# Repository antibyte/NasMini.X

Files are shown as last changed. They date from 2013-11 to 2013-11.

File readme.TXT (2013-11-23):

Single Chip Nascom 2 Emulator

Credits:
Z80 Emulation :         : Marat Fayzullin http://fms.komkon.org/EMUL8/
Video and PS/2 based on : Katsumi http://hp.vector.co.jp/authors/VA016157/
SD & FAT Filesystem     : Elm Chan, Aiden Morrison, Riccardo Leonardi

What's working :

z80 CPU
24K RAM (2K used by video buffer and NAS-SYS)
10K ROM (2K NAS-SYS 3 and 8K Microsoft Basic)
Loading NAS format files from SD card(press F1)
Saving RAM to NAS format on SD card (press F2)
Composite Video 48x16 video output, advanced graphics character ROM is included.
PS/2 keyboard with special keys:
  F1 - Load NAS file from SD card (works for BASIC)
  F2 - Save RAM (0x0100-0x7000) as NAS file to SD card (works for BASIC)
  Scroll lock - Trigger NMI
Single step emulation
RS232 is partialy working. Received Data is corrupted, maybe hardware
problem, as is used a Bluetooth adapter. 

ToDo :

Cassette Emulation (real or/and SD)
RS232 bootloader (if possible)
Map Z80PIO access to I2C Port expander, or remaining physical pins ?

Speed:
Maybe slower than the real thing, but really usable.

Thoughts:
A PIC32MX250 is used featuring USB, but there is not enought space left for any
USB stack.
But as the price difference to the non-USB MX150 is negligible for small
projects, it may be good to have it on board for possible reuse in future
projects.

First steps:
Visit http://www.nascomhomepage.com/
 
Type "J" after start to jump to Microsoft Basic
Most NAS files load to 0x01000. Type E1000 to run them

antibyte 11/2013

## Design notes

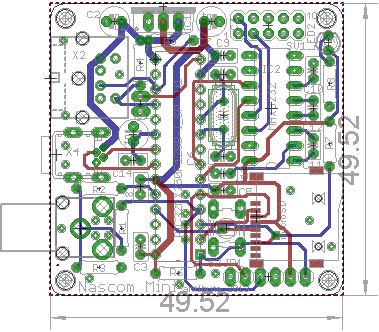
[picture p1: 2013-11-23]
NasMini.png

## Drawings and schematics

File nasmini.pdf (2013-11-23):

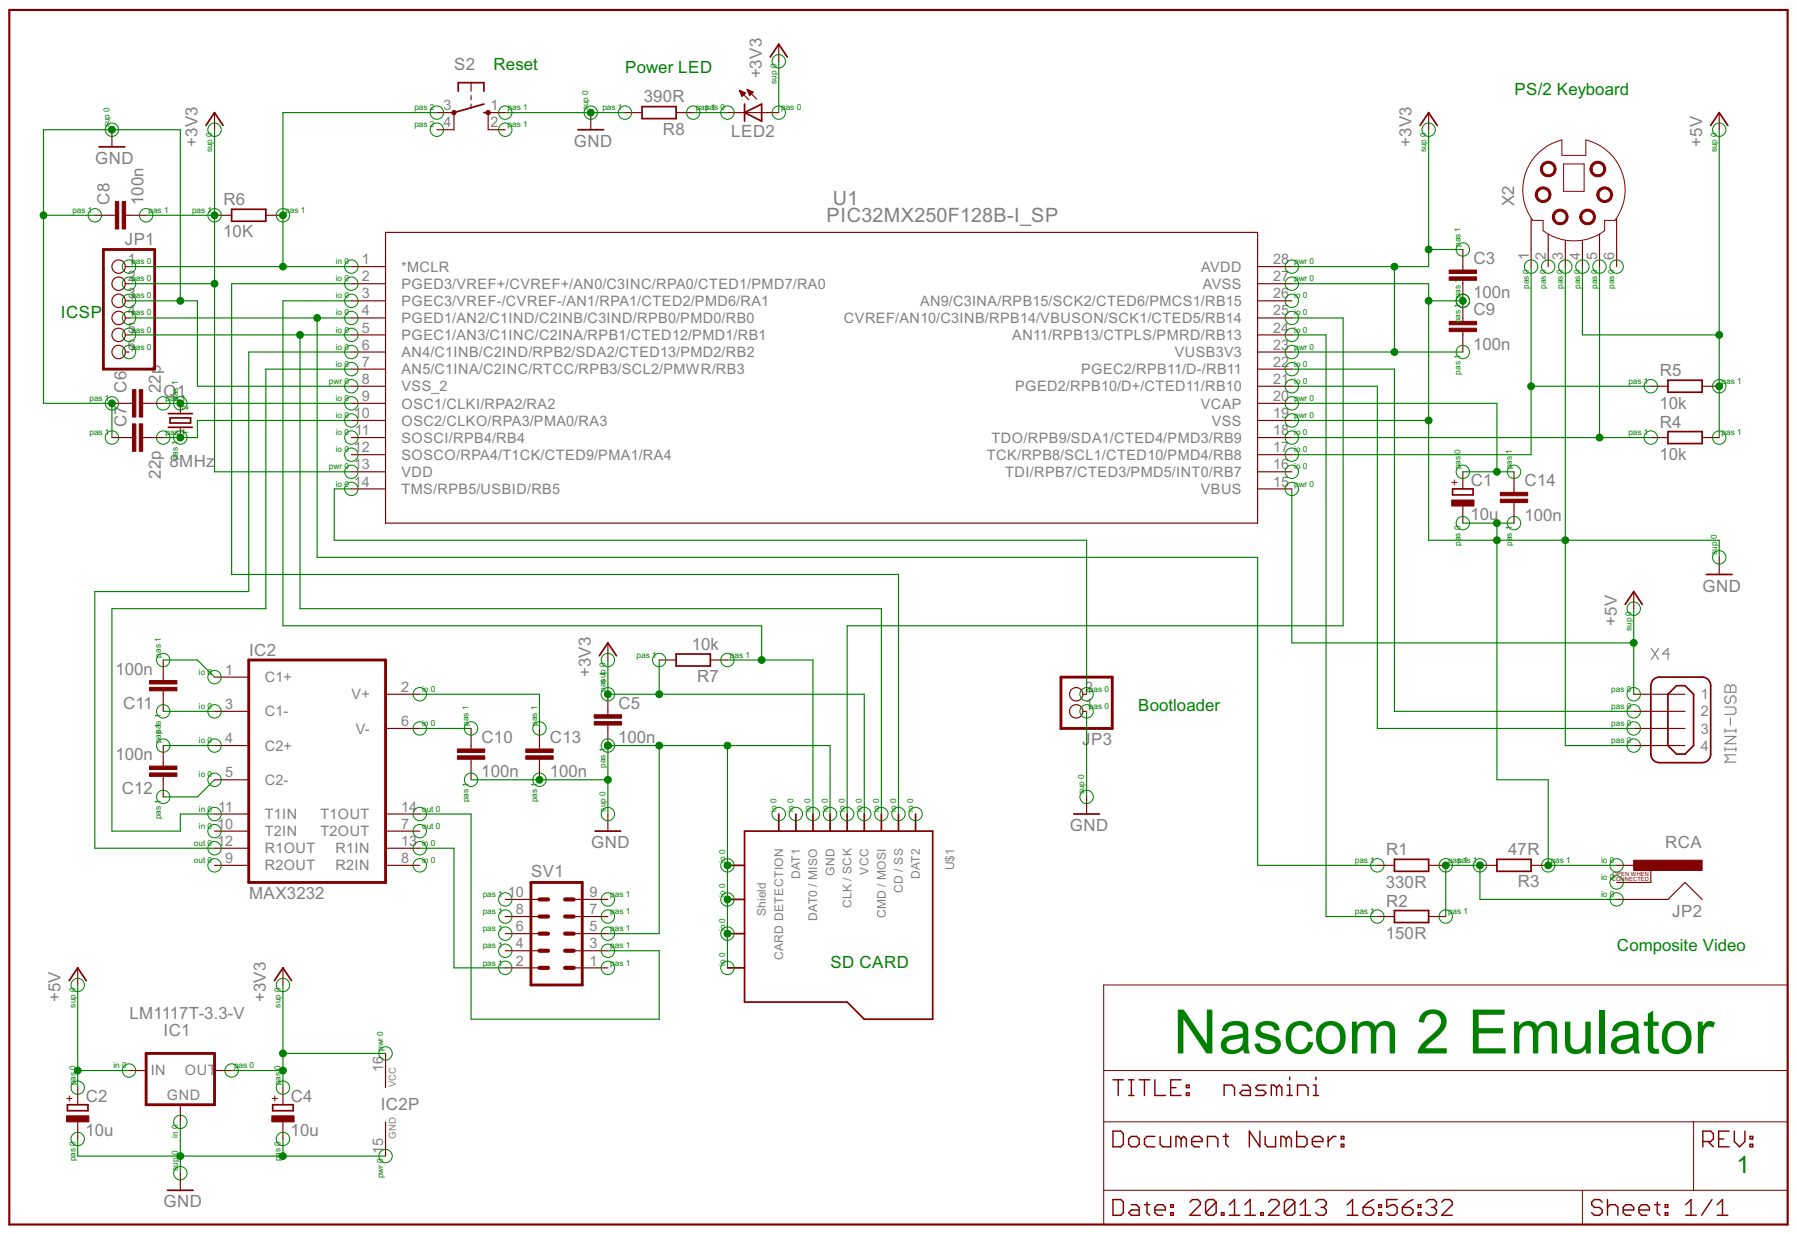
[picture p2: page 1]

17 TDO/RPB9/SDA1/CTED4/PMD3/RB9 io 0 | 10k
16 TCK/RPB8/SCL1/CTED10/PMD4/RB8

pas 1 pas 1

DAT2 CD / SS CMD / MOSI DAT0 / MISO

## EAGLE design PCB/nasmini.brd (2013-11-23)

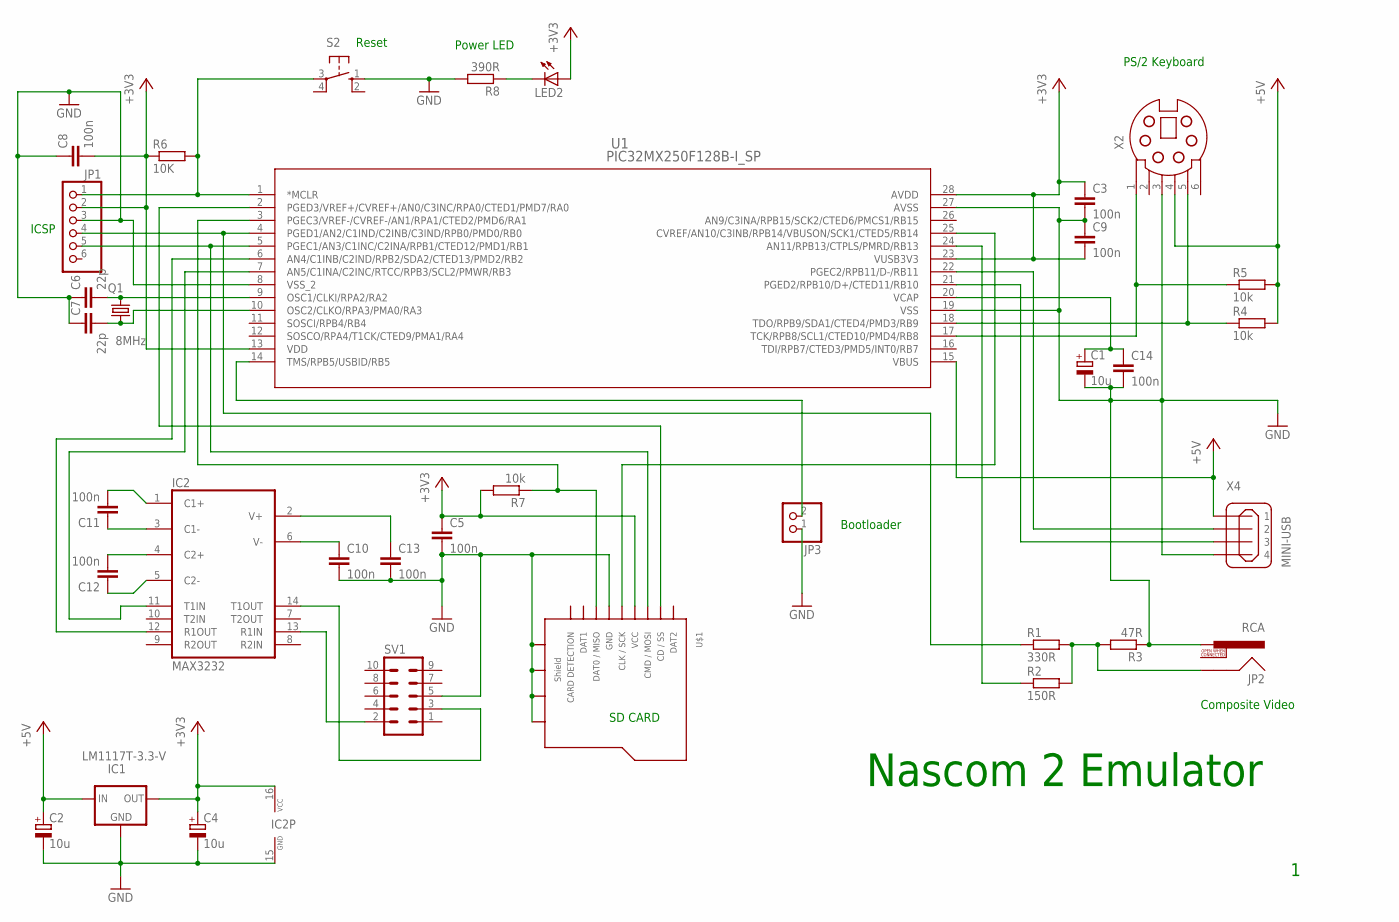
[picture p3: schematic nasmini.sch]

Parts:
C1, C2, C4: 10u; E2,5-5
C3, C5, C8, C9, C10, C11, C12, C13, C14: 100n; C025-025X050
C6, C7: 22p; C025-025X050
IC1: LM1117T-3.3-V; TO220V
IC2: MAX3232; DIL16
JP1: PINHD-1X6; 1X06
JP2: RCA
JP3: PINHD-1X2; 1X02
LED2: LED3MM
Q1: 8MHz; HC49/S
R1: 330R; 0207/7
R2: 150R; 0207/7
R3: 47R; 0207/7
R4, R5, R7: 10k; 0207/7
R6: 10K; 0207/7
R8: 390R; 0207/7
S2: 10-XX; B3F-10XX
SV1: MA05-2
U1: PIC32MX250F128B-I_SP; SPDIP28_300MC
U$1: MICROSD_CARD_POLLIN; MR**-AP*03**
X2: MDSSV-F06; SSV-BC06
X4: MINI-USB; 85-32006-201-1

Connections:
+3V3: C3.1, C4.+, C5.1, C8.2, C9.2, IC1.2 (OUT), IC2.16 (VCC), JP1.2, LED2.A, R6.1, R7.2, U1.13 (VDD), U1.23 (VUSB3V3), U1.28 (AVDD), U$1.VCC
+5V: C2.+, IC1.3 (IN), R4.2, R5.2, U1.15 (VBUS), X2.4, X4.1
GND: C1.-, C2.-, C3.2, C4.-, C5.2, C6.1, C7.1, C8.1, C9.1, C10.2, C13.2, C14.2, IC1.1 (GND), IC2.15 (GND), JP1.3, JP2.PIN, JP3.1, R3.1, R8.2, S2.1 (S), SV1.5, U1.8 (VSS_2), U1.19 (VSS), U1.27 (AVSS), U$1.GND, U$1.SHD_1 (SHD1), U$1.SHD_2 (SHD2), U$1.SHD_3 (SHD3), U$1.SHD_4 (SHD4), X2.3, X4.4
unnamed: R5.1, U1.17 (TCK/RPB8/SCL1/CTED10/PMD4/RB8), X2.1
unnamed: R4.1, U1.18 (TDO/RPB9/SDA1/CTED4/PMD3/RB9), X2.5
unnamed: R2.1, U1.24 (AN11/RPB13/CTPLS/PMRD/RB13)
unnamed: JP3.2, U1.14 (TMS/RPB5/USBID/RB5)
unnamed: JP2.SHELL, R1.2, R2.2, R3.2
unnamed: IC2.13 (R1IN), SV1.2
unnamed: C1.+, C14.1, U1.20 (VCAP)
unnamed: JP1.4, R1.1, U1.4 (PGED1/AN2/C1IND/C2INB/C3IND/RPB0/PMD0/R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)
unnamed: JP1.1, R6.2, S2.3, U1.1 (*MCLR)
unnamed: U1.25 (CVREF/AN10/C3INB/RPB14/VBUSON/SCK1/CTED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), U$1.CLK (CLK/SCK)
unnamed: U1.2 (PGED3/VREF+/CVREF+/AN0/C3INC/RPA0/CTED1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), U$1.DAT3/CS (CD/SS)
unnamed: R7.1, U1.3 (PGEC3/VREF-/CVREF-/AN1/RPA1/CTED2/PMD6/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), U$1.DAT0 (DAT0/MISO)
unnamed: JP1.5, U1.5 (PGEC1/AN3/C1INC/C2INA/RPB1/CTED12/PMD1/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), U$1.CMD (CMD/MOSI)
unnamed: U1.21 (PGED2/RPB10/D+/CTED11/RB10), X4.3
unnamed: C7.2, Q1.1, U1.10 (OSC2/CLKO/RPA3/PMA0/RA3)
unnamed: C6.2, Q1.2, U1.9 (OSC1/CLKI/RPA2/RA2)
unnamed: U1.22 (PGEC2/RPB11/D-/RB11), X4.2
unnamed: C13.1, IC2.2 (V+)
unnamed: C10.1, IC2.6 (V-)
unnamed: C12.1, IC2.5 (C2-)
unnamed: C12.2, IC2.4 (C2+)
unnamed: C11.1, IC2.3 (C1-)
unnamed: C11.2, IC2.1 (C1+)
unnamed: IC2.11 (T1IN), U1.7 (AN5/C1INA/C2INC/RTCC/RPB3/SCL2/PMWR/RB3)
unnamed: IC2.12 (R1OUT), U1.6 (AN4/C1INB/C2IND/RPB2/SDA2/CTED13/PMD2/R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)
unnamed: LED2.K (C), R8.1
unnamed: IC2.14 (T1OUT), SV1.3

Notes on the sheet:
Composite Video
PS/2 Keyboard
Nascom 2 Emulator
ICSP
SD CARD
Power LED
Reset
Bootloader

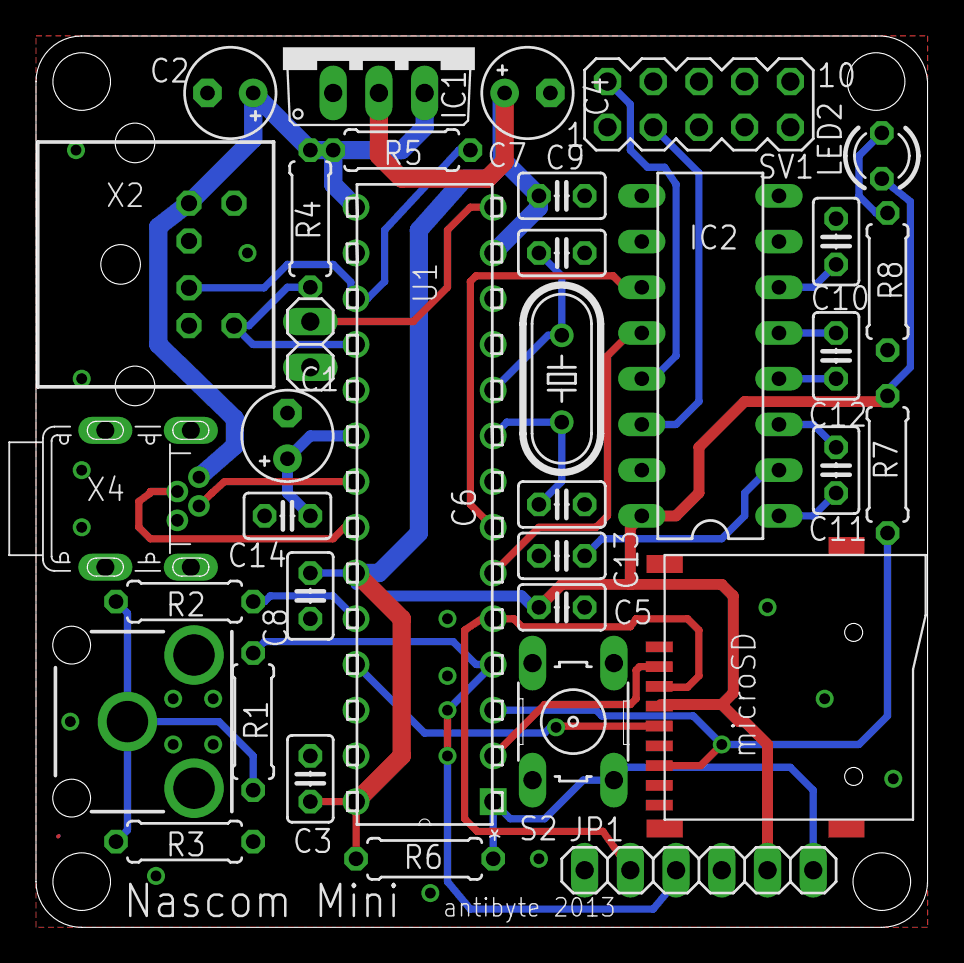
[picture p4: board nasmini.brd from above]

Board: 2 copper layers, 49.5 x 49.5 mm, 35 parts (0 on the bottom side), 30 nets.

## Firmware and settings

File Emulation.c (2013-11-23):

/* 
 * File:   Emulation.c
 * 
 * Authors and License :
 * Z80 Emulation:  Marat Fayzullin - free for noncommercial use
 * Video, PS/2 : Katsumi - licenced under LGPL 
 * FAT Filesystem : Elm Chan - free, unrestricted use
 * PIC32 FAT FS adaption : Aiden Morrison, Riccardo Leonardi
 * Nascom emulation : antibyte - free, unrestricted use
 *
 */

#define GetSystemClock()     (48000000ul)
#define GetPeripheralClock()    (GetSystemClock())
#define GetInstructionClock()   (GetSystemClock())

#include <stdio.h>
#include <stdlib.h>
#include <plib.h>
#include <peripheral/osc.h>
#include <peripheral/system.h>

#include "./Z80/Z80.h"
#include "./Z80/GenericTypeDefs.h"
#include "./Z80/Compiler.h"
#include "./z80/msbasic.h"
#include "./z80/nsys3.h"
#include "./Z80/Compiler.h"

#include "./emulation.h"
#include "./Video/video.h"
#include "./ps2.h"
#include "./fatfs/ff.h"
#include "./fatfs/diskio.h"
#include "./uart.h"
#include <sys/attribs.h>

/*
 * 
 */
#pragma config PMDL1WAY = OFF           // Allow multiple reconfigurations
#pragma config IOL1WAY  = OFF           // Allow multiple reconfigurations
#pragma config FPLLIDIV = DIV_2
#pragma config FPLLMUL  = MUL_24
#pragma config FPLLODIV = DIV_2
#pragma config FPBDIV   = DIV_1         // Peripheral Clock divisor
#pragma config UPLLEN   = OFF            // USB PLL Enable
#pragma config UPLLIDIV = DIV_2         // USB PLL Divider
#pragma config FVBUSONIO = OFF          // VBUS pin control
#pragma config FUSBIDIO = OFF           // USBID pin control
#pragma config FWDTEN   = OFF           // Watchdog Timer
#pragma config WDTPS    = PS1           // Watchdog Timer Postscale
#pragma config FCKSM    = CSDCMD        // Clock Switching & Fail Safe Clock Monitor
#pragma config OSCIOFNC = OFF           // CLKO Enable
#pragma config POSCMOD  = HS            // Primary Oscillator
#pragma config IESO     = OFF           // Internal/External Switch-over
#pragma config FSOSCEN  = OFF           // Secondary Oscillator Enable
#pragma config FNOSC    = PRIPLL        // Oscillator Selection
#pragma config CP       = OFF           // Code Protect
#pragma config BWP      = OFF           // Boot Flash Write Protect
#pragma config PWP      = OFF           // Program Flash Write Protect
#pragma config ICESEL   = ICS_PGx1      // ICE/ICD Comm Channel Select
#pragma config JTAGEN   = OFF           // Disable JTAG

#ifdef __DEBUG
#pragma config DEBUG = ON				// Background Debugger ON or OFF
#else
#pragma config DEBUG = OFF				// Background Debugger ON or OFF
#endif


unsigned char memory[maxmem];   // the emulated memory
char keyscan_counter;           // row counter for keymatrix scan
char key_reset;                 // reset keymatrix counter
unsigned char tape_led=0;       // tape_led state
unsigned char single_step=0;    // single_step circuit state
unsigned char serial_data=0;
unsigned char mounted=0;
unsigned char have_disk=0;
unsigned char loadrequest=0;
unsigned char fileNname[15];    // filename buffer

FRESULT FOpenRes;

Z80 engine;

FATFS Fatfs;
FATFS *fs;				/* Pointer to file system object */
FIL file;               		/* File objects */
volatile BYTE rtcYear = 111, rtcMon = 11, rtcMday = 22;	// RTC starting values
volatile BYTE rtcHour = 0, rtcMin = 0, rtcSec = 0;

//Work registers for fs command
DWORD acc_size;			/* Work register for fs command */
WORD acc_files, acc_dirs;
FILINFO Finfo;
const BYTE ft[] = {0,12,16,32};

#define TOGGLES_PER_SEC		1000
#define CORE_TICK_RATE	       (GetSystemClock()/2/TOGGLES_PER_SEC)


int main(int argc, char** argv) {

    SYSTEMConfig(GetSystemClock(), SYS_CFG_WAIT_STATES | SYS_CFG_PCACHE);

   /* USBDeviceInit();
    if ( USBGetDeviceState() == DETACHED_STATE ) {
        USBDeviceAttach();
    }*/

    ANSELA = 0;
    ANSELB = 0; //all ports digital

    INTEnableSystemSingleVectoredInt();
    INTEnableSystemMultiVectoredInt();

    // Software RTC for FAT Filesystem
    OpenCoreTimer(CORE_TICK_RATE);			// Open 1 ms Timer
    // set up the core timer interrupt with a prioirty of 2 and zero sub-priority
    mConfigIntCoreTimer((CT_INT_ON | CT_INT_PRIOR_2 | CT_INT_SUB_PRIOR_0));
    
    initVideo();                // start the video engine
    initPS2();                  // setup keyboard
    initUART();                 // setup RS232

    if (!disk_initialize(0))    // initialize sd card
    {
        have_disk=1;
        f_mount(&Fatfs,"/",1);
    }

    engine.IPeriod=500;         // Call 'LoopZ80' every 500 Z80 clocks
    ResetZ80(&engine);         
    uart_putc('X');
    while(1)
    {
      RunZ80(&engine);          // Start Z80 emulation
    }
    return (EXIT_SUCCESS);
}

void WrZ80(register word Addr,register byte Value) // handles Z80 memory writing
{
    word tladdr,vline,vcol;
    tladdr=(Addr-0x800);

    if (Addr>=0x0c00 && Addr<maxmem)
        memory[tladdr]=Value; // write to ram
    else if (Addr>=0x800 && Addr<0xc00)   // access to video ram ?
    {
        if (tladdr>9)   // visible area starts at vram+10
        {               // translate to video engine buffer
            vline=tladdr>>6;
            vcol=tladdr>73?tladdr%64-10:tladdr-10;
            if (vline<15 && vcol<49)
                VRAM[48+vline*48+vcol]=Value;
            if (vline==15 && vcol<48)   // last line in vram is first on screen
                VRAM[vcol]=Value;
        }
        memory[tladdr]=Value;   // store in ram
    }
    return;

}
byte RdZ80(register word Addr)  // handles Z80 memory reading
{
    if (Addr < 0x800)                // 0x000-0x800 is monitor rom
        return nsysrom[Addr];
    else if (Addr < 0x800+maxmem)    // 0x1000-0x7000 is ram
        return memory[Addr-0x800];

    if (Addr>=0xe000)                // 0xe000-0xffff is basic rom
        return basrom[Addr-0xe000];
    return 0;
}

void OutZ80(register word Port,register byte Value)

{
    word pt = Port & 0x00ff;

    switch(pt)
    {
        case 0:
            if (Value&0x01)
                keyscan_counter++;  // scan next keyboard row
            if (Value&0x02)
                keyscan_counter=0;  // reset keyboard matrix counter
            tape_led=!!(Value&0x10);
            if (Value&0x08)         // Single step circuit triggered ?
                engine.Trap=1;
            break;
        case 1:
            uart_putc(Value);
            break;

    }
}

byte InZ80(register word Port)

{
    word pt = Port & 0x00ff;

    switch(pt)
    {
        case 0:         // keyboard matrix scan result (inverted)
             return ~(keyscan_buffer[keyscan_counter]);
        case 1:         // read serial data
            if (uart_rx_count)
            {
                
                //uart_rx_count--;
                return uart_rx_buff[--uart_rx_count];
            }
            return 0;
    
        case 2:         // read serial port status byte
             return 64 | (uart_rx_count ? 128:0);

        default:
             return 0;
    }
}

word LoopZ80(register Z80 *R)   // called periodically from Z80 emulation

{
    getkey();                   // Check for keypress

    if (key_nmi)                // scroll lock was pressed, trigger NMI
    {
        key_nmi=0;
        return INT_NMI;
    }

    if (edit_mode && have_disk)           // F1 - User wants to load "*.NAS" file
    {
        if (req_action==1)
        {
            if (get_filename(fileNname, "NAS format file loading:" ) && !!fileNname[0])
            {
                if (open_file(fileNname,FA_READ))
                {
                    load_nas();
                    close_file();
                    return INT_NONE;
                } else
                    if (!!fileNname[0]);
                        user_info("Fatal Error:", "Could not open the requested file !");
            }
        } else if (req_action==2)       // F2 - User wants to save to "*.NAS" file
        {
            if (get_filename(fileNname, "NAS format memory dump (0x1000-0x7000)." ) && !!fileNname[0])
            {
                if (open_file(fileNname,FA_WRITE))
                {
                    save_nas();
                    close_file();
                    return INT_NONE;
                } else
                    if (!!fileNname[0]);
                        user_info("Fatal error;", "Could not open the requested file !");
            }            
        }
        req_action=0;
    }

    if (tape_led && have_disk && !mounted)
    {
        // todo: cassette emulation
    }
        
    return INT_NONE;

}

void PatchZ80(register Z80 *R)
{
   
}

void save_nas()
{
    if (!have_disk)
        return;

    unsigned char haddr[4];
    unsigned char val[2];
    char eol[4]={0x08,0x08,0x0d,0x0a};
    char eofm[3]={'.',0x0d,0x0a};
    unsigned char r;
    int c;
    unsigned int cksum=0;
    unsigned int wcnt;

    for (c=0;c<maxmem-0x800;c+=8)
    {
        nas_val2hex(0x1000+c,haddr,4);
        cksum+=(0x1000+c)>>2&0x00ff;
        cksum+=(0x1000+c)&0x00ff;
        f_write(&file, &haddr,4,&wcnt);
        f_write(&file, " ",1,&wcnt);
        for (r=0;r<8;r++)
        {
            nas_val2hex(memory[0x800+c+r],val,2);
            cksum+=memory[0x800+c+r];
            f_write(&file, &val,2,&wcnt);
            f_write(&file, " ",1,&wcnt);
        }
        nas_val2hex(cksum&0x00ff,val,2);
        cksum=0;
        f_write(&file, val,2,&wcnt);
        f_write(&file, &eol,4,&wcnt);
    }
    f_write(&file, &eofm,3,&wcnt);
}

/* Load a file in NAS format
   Every line starts with the target addr. followed by
   eight bytes of data and a one byte checksum.
   ASCII format ----------------->|
   AAAA 01 02 03 04 05 06 07 08 09 0x08 0x08 0x0d 0x0a
   checksum is low byte of AA+AA+01 ... +08
   Last line contains only a dot '.' and CR/LF */

void load_nas()
{

    if (!have_disk)
        return;

    BYTE haddr[4];
    BYTE hval[2];
    WORD taddr;
    WORD tval;
    UINT bread=0;
    char l;

    for(;;)
    {
        f_read(&file,&haddr,4,&bread);
        if (haddr[0]=='.') // done if first char in line is a dot
            goto done;
        if (bread!=4) //EOF
            goto err;
        taddr=nas_hex2val(haddr,4);
        if (taddr<0x1000 || taddr>maxmem+0x1000)
        {
            printchar2(0,taddr>>8);
            printchar2(2,taddr&&0x00ff);
            //v_print(10);
            //v_print(haddr);
            while(1);
            user_info("Fatal Error:","Target address outside of allowed range.");
            return;
        }
        for (l=0;l<8;l++)
        {
            f_read(&file, &hval,1,&bread); //dummy (blank)
            f_read(&file, &hval,2,&bread);
            if (!!!bread) //EOF
                goto err;
            memory[taddr-0x800+l]=nas_hex2val(hval,2);
        }
        while (1)
        {
            f_read(&file, &hval,1,&bread);
            if (!bread) //EOF
                goto err;
            if (hval[0]==0x0a) // line finished
                break;
        }
    }
err:
    user_info("Fatal Error:","Unexpected end of file.");
done:
    return;

}

WORD nas_hex2val (char* haddr,BYTE len)
{
    int rval,i=0;
    while (len--)
    {
        rval<<=4;
        rval|=(haddr[i]<='9'?haddr[i]-'0':haddr[i]-'A'+10);
        i++;
    }
    return rval;
}

void nas_val2hex(WORD val, char* hex, BYTE len)
{
	int ch, i = 0;
	while (len--)
	{
		ch = val & 0x000f;
		hex[len] = (ch > 9 ? 'A' + ch-10 : '0' + ch);
			val >>= 4;
	}
}

unsigned char get_filename(char *fname,char *desc_text)
{
    BYTE x=0;
    save_vram();    // save a copy of the screen
    printchar(12);
    v_print(desc_text);
    printchar(10);
    v_print("Enter Filename or press ESC to exit. ");
    printchar(10);
    while (edit_keybuff!='*') // escape='*'
    {
        getkey();
        if (edit_newkey)
        {
            switch(edit_keybuff)
            {
                case('+'):  // enter
                    if (x==0)
                    {
                        fname[0]=0;
                    } else
                    {
                        memcpy(fname,VRAM+96,x);
                        fname[x]=0;
                    }
                    restore_vram();
                    edit_mode=edit_keybuff=edit_newkey=0;
                    return 1;
                 case ('-'):    // backspace
                    printchar (8);
                    if (x>0)
                        x--;
                    edit_newkey=0;
                    continue;
                default:
                    if (x<12)
                    {
                        edit_newkey=0;
                        printchar (edit_keybuff);
                        x++;
                    }
            }
        }
    }
    edit_mode=edit_keybuff=edit_newkey=0;
    restore_vram(); // restore original screen
    return 0;
}


unsigned char open_file (char *fname, unsigned char mode)
{
    FRESULT FOpenRes;
    long accessmode;
    accessmode=(mode==FA_READ)?(FA_READ | FA_OPEN_EXISTING):(FA_OPEN_ALWAYS | FA_CREATE_ALWAYS |FA_WRITE );
    FOpenRes=f_open(&file, fname, (BYTE)accessmode);
    return (FOpenRes==FR_OK)?1:0;
}

void close_file ()
{
    f_close(&file);
}

void user_info(char *info,char *text)
{
    edit_mode=1;
    save_vram();
    printchar(12);
    v_print(info);
    printchar (10);
    v_print(text);
    printchar (10);
    printchar (10);
    v_print("Press ESC to continue.");
    printchar(10);
    while (edit_keybuff!='*')
        getkey();
    restore_vram();
    edit_mode=0;
}


/*****************************************************************************
 * Function:  		void CoreTimerHandler(void)
 * PreCondition:
 * Input:           None
 * Output:          None
 * Side Effects:
 * Overview:        FatFs requires a 1ms tick timer to aid
 *					with low level function timing
 * Note:            Initial Microchip version adapted to work into ISR routine
 *****************************************************************************/
void __ISR(_CORE_TIMER_VECTOR, IPL2SOFT) CoreTimerHandler(void)
{
	static const BYTE dom[12] = {31, 28, 31, 30, 31, 30, 31, 31, 30, 31, 30, 31};
	static int div1k;
	unsigned char n;

	// clear the interrupt flag
	mCTClearIntFlag();
    // update the period
    UpdateCoreTimer(CORE_TICK_RATE);

	disk_timerproc();	// call the low level disk IO timer functions

	// implement a 'fake' RTCC
	if (++div1k >= 1000) {
		div1k = 0;
		if (++rtcSec >= 60) {
			rtcSec = 0;
			if (++rtcMin >= 60) {
				rtcMin = 0;
				if (++rtcHour >= 24) {
					rtcHour = 0;
					n = dom[rtcMon - 1];
					if ((n == 28) && !(rtcYear & 3)) n++;
					if (++rtcMday > n) {
						rtcMday = 1;
						if (++rtcMon > 12) {
							rtcMon = 1;
							rtcYear++;
						}
					}
				}
			}
		}
	}
}


/*********************************************************************
 * Function:  		DWORD get_fattime(void)
 * PreCondition:
 * Input:           None
 * Output:          Time
 * Side Effects:
 * Overview:        when writing fatfs requires a time stamp
 *					in this exmaple we are going to use a counter
 *					If the starter kit has the 32kHz crystal
 *					installed then the RTCC could be used instead
 * Note:
 ********************************************************************/
DWORD get_fattime(void)
{
	DWORD tmr;

	INTDisableInterrupts();
	tmr =	  (((DWORD)rtcYear - 80) << 25)
			| ((DWORD)rtcMon << 21)
			| ((DWORD)rtcMday << 16)
			| (WORD)(rtcHour << 11)
			| (WORD)(rtcMin << 5)
			| (WORD)(rtcSec >> 1);
	INTEnableInterrupts();

	return tmr;
}


/** EOF main.c *************************************************/

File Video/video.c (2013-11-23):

/*
   This program is provided under the LGPL license ver 2.
   Written by Katsumi.
   http://hp.vector.co.jp/authors/VA016157/
   kmorimatsu@users.sourceforge.jp
   -------
   Converted to PAL Timings and NASCOM resolution by antibyte 11/2013
   This creates a 48x16 character display.
   Font is 8x16, so final resolution is 384x256
   Allmost all modern TV's should be able to handle both PAL and NTSC.
   Nascom produced a 8x12 cut font version for sale in NTSC regions.

 ****** NOTE: ignore values in comments, most are still ntsc based *****

 
 */

#include <plib.h>
#include "video.h"
#include "cgrom.h"
#include "./../ps2.h"
#include "./../emulation.h"


/*

PAL:

  	Raster frequency is 15625 hz, so one raster takes 64 usecs.
	Use 3072 clocks, resulting in 15625 hz
	Note that 512 clocks of 8 MHz (=SPI clock speed) also produces the same frequency.

 */

/*	Minimum time between two interruption events is 2.3 usecs,
	that corresponds to 92 clocks.
*/

// RB0=Sync
#define sync LATBbits.LATB0 //remapped for better PCB layout ,was 13
#define toggleSync() LATBINV=0x01 // remapped, was 2000
#define hclocks 3072

unsigned char VRAM[84*16];  // video buffer
unsigned char VRAM2[84*16]; // video backup buffer

void initVideo(){
	unsigned long i;
        for (i=0;i<0x0300;i++) {
		VRAM[i]=32;
	}
	g_ntscVisible=1;
	g_Vsync=1;
	sync=1;

	// RB13 and RA4 are output pins
	TRISBbits.TRISB0=0; // was A4
	TRISBbits.TRISB13=0;

	// Timer2 is used for sync signal
	// On, Stop in Idle Mode, PBCLK, 1:1 prescale, 16-bit mode
	// Enable interrupt as priority 7
	TMR2=0;
	PR2=0xFFFF;
	T2CON=0xA000;
	T2CONbits.ON=1;
	IPC2bits.T2IP=7;
	IPC2bits.T2IS=0;
	IFS0bits.T2IF=0;
	IEC0bits.T2IE=1;

	// Timer4 is used for video signal
	// Off, Stop in Idle Mode, PBCLK, 1:2 prescale, 16-bit mode
	// Enable interrupt as priority 6
	TMR4=0;
	PR4=0xFFFF;
	T4CON=0x2010;
	IPC4bits.T4IP=6;
	IPC4bits.T4IS=0;
	IFS0bits.T4IF=0;
	IEC0bits.T4IE=1;

	// SPI2 module settings follow
	// PBCLOCK, Enable SPI2, Stop in Idle Mode, Enable SDO, 32 bit mode,
	// SS pin not used, Master mode, Disable SDI
	// SPI clock=REFCLK/(2x(SPI2BRG+1))=8 Mhz. (REFCLK=48 Mhz; SPI2BRG=2)
	// All extended setting are off (SPI2CON2).

	SPI2CON=0x0100A83C;
	SPI2CON2=0x0300;
	SPI2BRG=2;
	// Output SDO2 RB13 - remapped, was RA4
        RPB13R=0x04;
}

/*	PAL Sync signals:
	raster 1-3: L for 2.3 usecs, H for 29.5 usec, L for 2.3 usecs, H for 29.5 usec
	(110)         (110)
	2.3u__________2.3u__________                 110+1414+110+1414=3048
	|__|          |__|          
	       29.5u         29.5u
          (1414)        (1414)

	raster 4-6: L for 27.1 usecs, H for 4.7 usec, L for 27.1 usecs, H for 4.7 usec
      (1299)        (1299)
	   27.1u    __   27.1u    __                 1299+225+1299+225=3048
	|__________|  |__________|  
	           4.7u          4.7u
              (225)         (225)

	raster 7-9: L for 2.3 usecs, H for 29.5 usec, L for 2.3 usecs, H for 29.5 usec
	(110)         (110)
	2.3u__________2.3u__________                 110+1414+110+1414=3048
	|__|          |__|          
	       29.5u         29.5u
          (1414)        (1414)

	raster 10-262: H for 1.5 usecs, L for 4.7 usecs, H for 57.4 usecs
      (225)
	___4.7u_____________________                 72+225+2751=3048
	   |__|          
	1.65u          57.4u 57,65
    (72)         (2751)

	This must produces 16275 Hz sync signal.
	Following intterupt function takes about 1 micro second.
	This will be 0.5 micro second if IPL7SRS will be used.
*/

#define bporch 79
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

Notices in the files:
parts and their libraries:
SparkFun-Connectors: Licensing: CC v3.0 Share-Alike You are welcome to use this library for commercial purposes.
